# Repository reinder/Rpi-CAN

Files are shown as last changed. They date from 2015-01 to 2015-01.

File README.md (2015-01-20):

# Rpi-CAN
Rpi-CAN is a CAN-bus extension board for Raspberry Pi.

The board runs completly on 3.3V and is powered by the Raspberry Pi 3.3 V rail.
Alternativly it can be powered by the Raspberry Pi 5V rail.

The Rpi-CAN uses the [Microchip MCP2515 CAN controller](www.microchip.com/solutionsmcp2515) via SPI.
The MCP2515 is supported by Linux and Raspbian, allthough support for the MCP2515 is missing in the default Raspbian kernel.

**NOTE:** There is no galvanic isolation between the CAN-bus and the Raspberry Pi!

## Components
- R1: Resistor, 0 Ohm, 0805 (Optional: only if directly powered from the 3.3 V rail.)
- R2: Resistor, 120 Ohm, 0805 
- R3: Resistor, 10 kOhm, 0805 
- R4: Resistor, 10 kOhm, 0805 
- R5: Resistor, 0 Ohm, 0805 (Optional: for connecting *optional ground* to the Raspberry Pi ground) 
- R6: Resistor, 0 Ohm, 0805 (Optional: for connecting *CAN-ground* to the Raspberry Pi ground)
- R7: Resistor, 0 Ohm, 0805 (Optional: for connecting *optional power* to the Raspberry Pi 5V rail)
- C1: Ceramic Capacitor, 100 nF, 0805
- C1: Ceramic Capacitor, 100 nF, 0805
- C5: Ceramic Capacitor, 18 pF, 0805
- C6: Ceramic Capacitor, 18 pF, 0805
- C9: Ceramic Capacitor, 100 nF, 0805 (Optional: only if powered from 5 V rail.)
- C10: Ceramic Capacitor, 100 nF, 0805 (Optional: only if powered from 5 V rail.)
- Q1: Crystal, 20 MHz, SM49
- IC1: CAN tranciever, SN65HVD233-HT, SO-8
- IC2: CAN controller, MCP2515, SO-18W
- IC3: Voltage regulator 3.3V, XC6221B332MR, SOT25 (Optional: only if powered from 5 V rail.)
- JP1: 3 pin jumper, RM254
- JP2: 2 pin jumper, RM254
- JP3: 3 pin jumper, RM254
- X2: Pin header 2x13 female, RM254 
- X3: D-sub 9 pin male, solder

## Jumpers
- JP1 is for selecting the SPI chip select (CS0 or CS1).
- JP2 is for enabling/disabling the 120 Ohm bus temination resitor.
- JP3 is for selecting the interrupt GPIO (23 or 24).

## CAN-bus connector pinout
1. Not connected
2. CAN Low
3. CAN ground
4. Not connected
5. Not connected
6. Optional ground
7. CAN High
8. Not connected
9. Optional power

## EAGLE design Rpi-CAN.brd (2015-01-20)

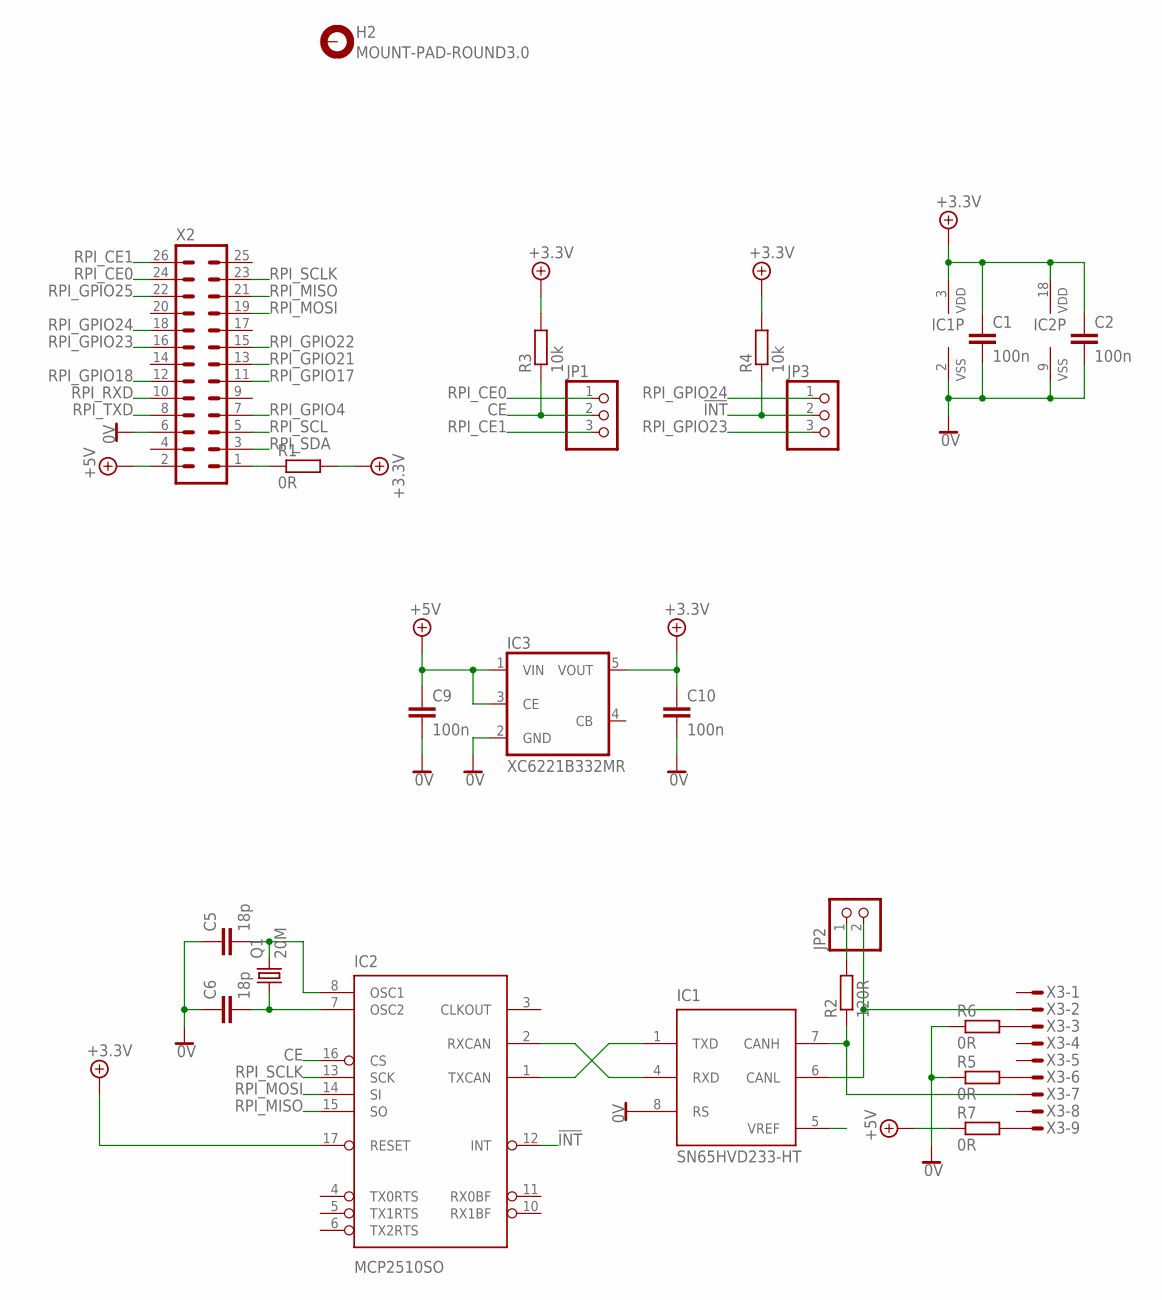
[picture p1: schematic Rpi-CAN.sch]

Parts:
C1, C2, C9, C10: 100n; C0805
C5, C6: 18p; C0805
H2: MOUNT-PAD-ROUND3.0; 3,0-PAD
IC1: SN65HVD233-HT; SO-08
IC2: MCP2510SO; SO-18W
IC3: XC6221B332MR; SOT25
JP1, JP3: PINHD-1X3; 1X03
JP2: PINHD-1X2; 1X02
Q1: 20M; SM49
R1, R5, R6, R7: 0R; R0805
R2: 120R; R0805
R3, R4: 10k; R0805
X2: MA13-2
X3: M09DS; M09D

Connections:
0V: C1.2, C2.2, C5.1, C6.1, C9.2, C10.2, IC1.2 (VSS), IC1.8 (RS), IC2.9 (VSS), IC3.2 (GND), R5.1, R6.1, X2.6
!INT: IC2.12 (INT), JP3.2, R4.1
+3.3V: C1.1, C2.1, C10.1, IC1.3 (VDD), IC2.17 (RESET), IC2.18 (VDD), IC3.5 (VOUT), R1.2, R3.2, R4.2
+5V: C9.1, IC3.1 (VIN), IC3.3 (CE), R7.1, X2.2
CE: IC2.16 (CS), JP1.2, R3.1
unnamed: IC1.6 (CANL), JP2.2, X3.2
unnamed: R5.2, X3.6
unnamed: IC1.7 (CANH), R2.1, X3.7
unnamed: R6.2, X3.3
unnamed: R7.2, X3.9
unnamed: IC1.4 (RXD), IC2.2 (RXCAN)
unnamed: IC1.1 (TXD), IC2.1 (TXCAN)
unnamed: C5.2, IC2.8 (OSC1), Q1.2
unnamed: C6.2, IC2.7 (OSC2), Q1.1
unnamed: JP2.1, R2.2
unnamed: R1.1, X2.1
RPI_CE0: JP1.1, X2.24
RPI_CE1: JP1.3, X2.26
RPI_GPIO4: X2.7
RPI_GPIO17: X2.11
RPI_GPIO18: X2.12
RPI_GPIO21: X2.13
RPI_GPIO22: X2.15
RPI_GPIO23: JP3.3, X2.16
RPI_GPIO24: JP3.1, X2.18
RPI_GPIO25: X2.22
RPI_MISO: IC2.15 (SO), X2.21
RPI_MOSI: IC2.14 (SI), X2.19
RPI_RXD: X2.10
RPI_SCL: X2.5
RPI_SCLK: IC2.13 (SCK), X2.23
RPI_SDA: X2.3
RPI_TXD: X2.8

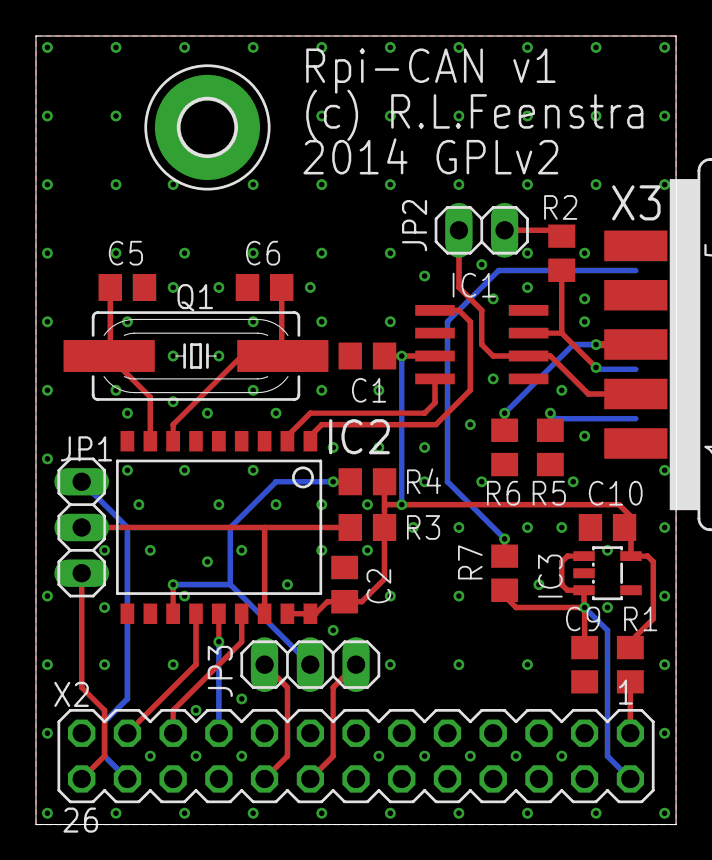
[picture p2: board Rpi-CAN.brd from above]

Board: 2 copper layers, 35.6 x 43.8 mm, 23 parts (0 on the bottom side), 23 nets.

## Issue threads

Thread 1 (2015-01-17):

Correct mount pad location

reinder, 2015-01-17:
Mount pad location is wrong, isn't alligned with Raspberry Pi mount hole.

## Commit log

2015-01-17 Initial commit, as designed and produced in june 2014.
    [Rpi-CAN.brd, Rpi-CAN.sch]
2015-01-20 Added resitor for connecting Raspberry Pi 5V rail to CAN optional power.
    [Rpi-CAN.brd, Rpi-CAN.sch]
2015-01-20 Added CAN-bus connector pinout.

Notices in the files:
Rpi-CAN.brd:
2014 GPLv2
